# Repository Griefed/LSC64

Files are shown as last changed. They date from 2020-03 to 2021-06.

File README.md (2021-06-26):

# **This is still a WIP**
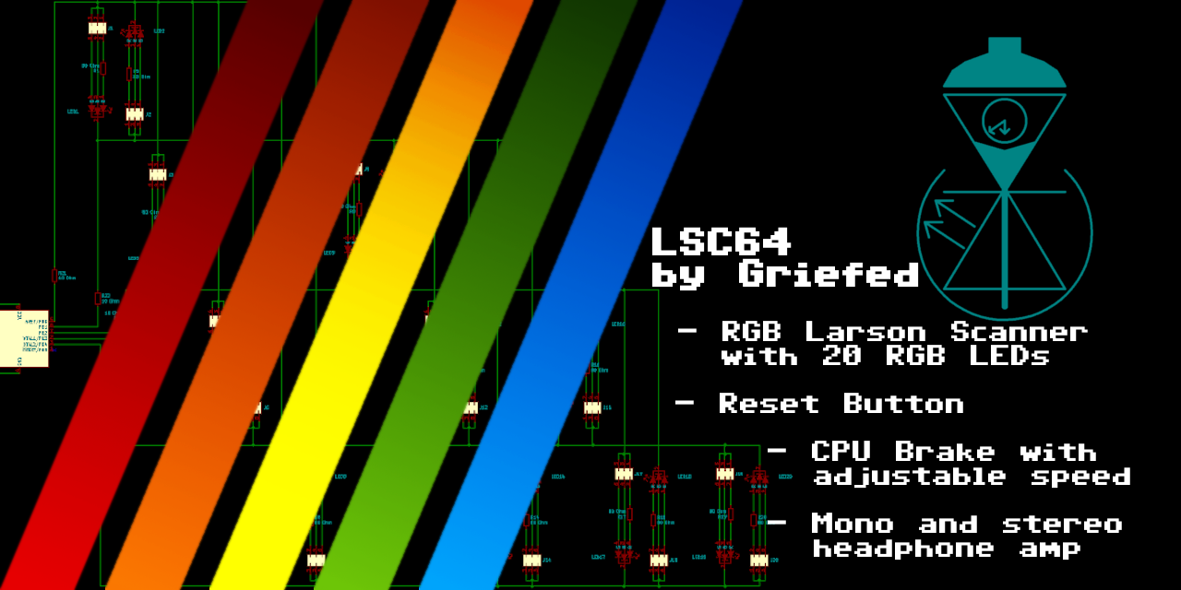
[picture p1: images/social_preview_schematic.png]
Social_Preview

# **This is still a WIP**

# Sources, GitHub, GitLab and Mirroring and all that good stuff

Repositories on GitHub are now for issues only. I've set up my own installation of GitLab and moved all my repositories over to [Git.Griefed.de](https://git.griefed.de/users/Griefed/projects). Make sure to check there first for the latest code before opening an issue on GitHub.

For questions, you can always join my [Discord server](https://discord.griefed.de) and talk to me there.

---

[[_TOC_]]

**This has yet to be tested IRL. I currently don't have the funds to procure the PCB and parts in order to build and test it. No guarantee on anything as of yet. Also, the code for the Attiny85 has yet to be written, reason: See above.**
----
## Features

A PCB to enhance your C64C with various things:
- A Larson Scanner with RGB LEDs, so you can configure it to your liking!
- An Expansion Port reset circuit. You just need to connect a button and off you go!
- A CPU brake: Throttle your CPU and slow down your game during the really tricky bits!
- Mono & Stereo Headphone Amp. Listen to the beautiful SID sounds with your headphones. Either in mono or in stereo, if you have an FPGA SID!

## Assembly

After getting the PCB printed the the printing service of your choice and getting all the parts from the vendor of your choice, take a good look at [the interactive BOM](BOMinteractive.html).
It's a nice interactive overview of the whole PCB, which helps you placing all your parts where they're supposed to be! (You need to download )
Thanks to the Open Scope Project on GitHub for this amazing KiCad plugin: [InteractiveHtmlBom](https://github.com/openscopeproject/InteractiveHtmlBom)

## Connecting your LSC64

### Larson Scanner

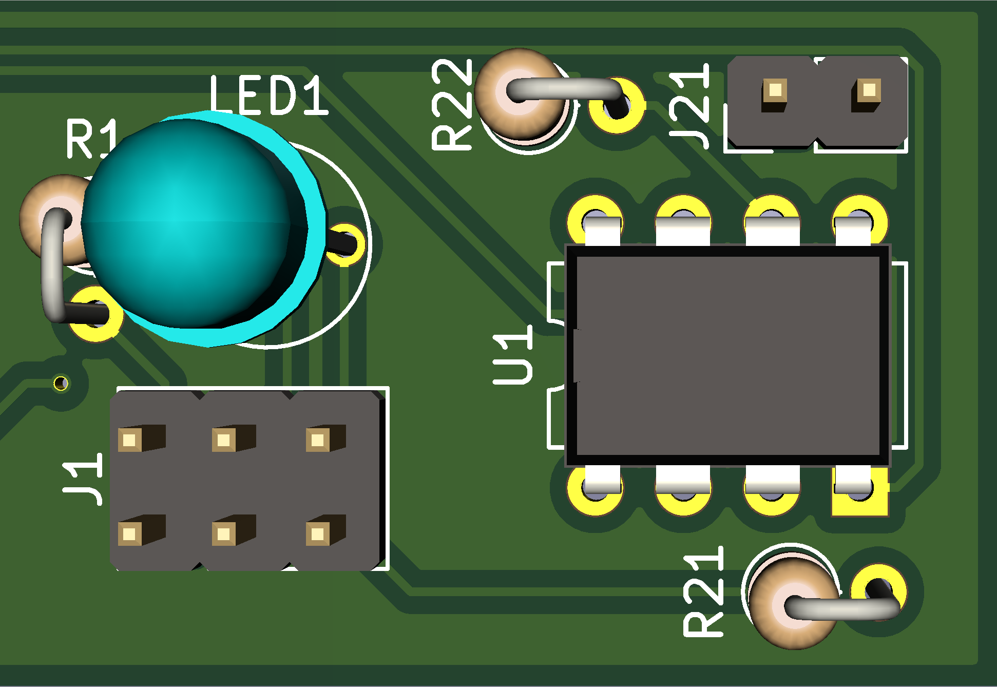
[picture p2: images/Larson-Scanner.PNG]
Larson


For information about the pin layout of the power connector, check out: [C64 Power Supply Connector](https://www.c64-wiki.com/wiki/Power_Supply_Connector)

The bottom 3 pins of J1 to J20 are all the same. The top 3 pins of J1 to J20 represent one colour of the RGB LED each.
From left to right: red, blue green.
So, to set the colours of the LED:

| From | Of | To | Of | Colour |
|:---|:---:|:---:|---:|:---:|
| Any of J21 | LSC64 | Pin 5 (+5V DC) | [C64 Power Supply Connector](https://www.c64-wiki.com/wiki/Power_Supply_Connector)| -x- |
| Any of J21 | LSC64 | J24 | LSC64 | -x- |
| Any of J26 | LSC64 | Pin 2 (GND) | [C64 Power Supply Connector](https://www.c64-wiki.com/wiki/Power_Supply_Connector)| -x- |
| J1 to J20 - Bottom Row| LSC64 | J1 to J20 - Top Left | LSC64 | Red |
| J1 to J20 - Bottom Row| LSC64 | J1 to J20 - Top Middle | LSC64 | Blue |
| J1 to J20 - Bottom Row| LSC64 | J1 to J20 - Top Right | LSC64 | Green  |

**Caution: Enabling more than one colour may result in the LED not lighting up at all. That is due to the output capacity of the Attiny85.**

**I recommend you only have one colour per LED enabled at all times.**

Special thanks to Luc Volders for the explanations and examples on how to build a charlieplexed Larson Scanner: [Luc's Tech Blog post about his Larson Scanner](https://lucstechblog.blogspot.com/2017/09/charlieplexing.html)

### The Reset Button

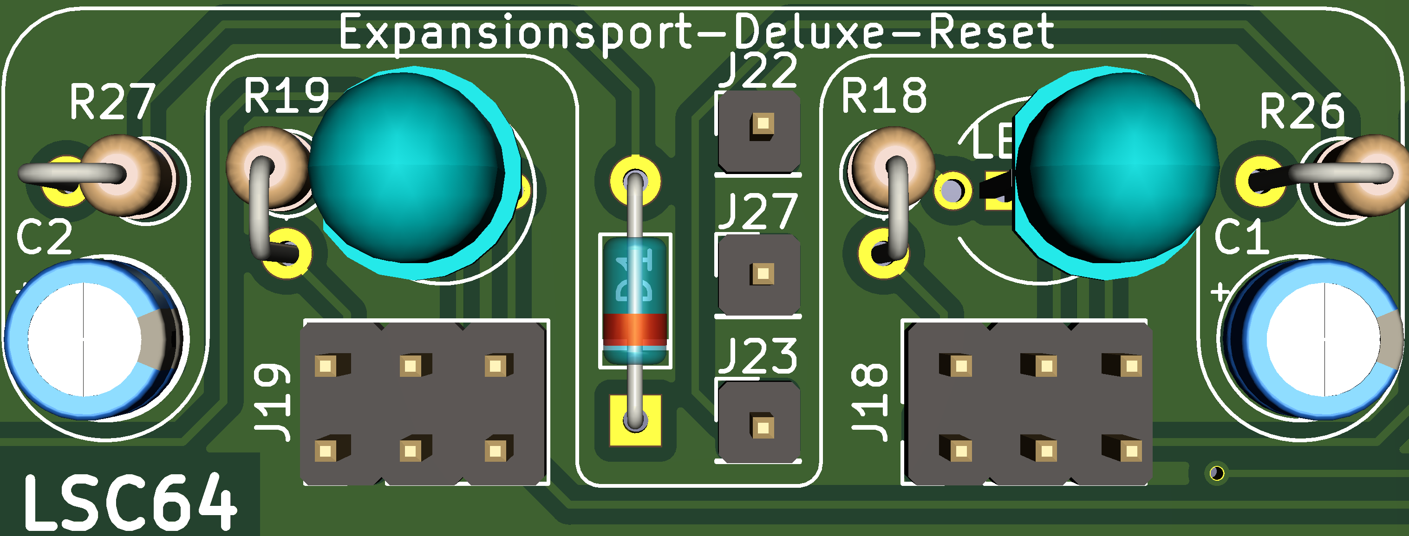
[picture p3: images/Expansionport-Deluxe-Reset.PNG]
Reset


| From | Of | To | Of |
|:---|:---:|:---:|---:|
| J22 | LSC64 | Pin C (RESET) | [C64 Expansion Port](https://www.c64-wiki.com/wiki/Expansion_Port) |
| J27 | LSC64 | Pin 9 (EXROM) | [C64 Expansion Port](https://www.c64-wiki.com/wiki/Expansion_Port) |
| J23 | LSC64 | Pin 1 | [Button](https://www.digikey.de/product-detail/de/e-switch/RP3502MABLK/EG1932-ND/280450?cur=EUR&lang=de)|
| Any of J26 | LSC64 | Pin 2 | [Button](https://www.digikey.de/product-detail/de/e-switch/RP3502MABLK/EG1932-ND/280450?cur=EUR&lang=de)|

Special thanks to AntaBaka for the schematics and the idea: [Expansionport-Deluxe-Reset](http://pitsch.de/stuff/c64/index_c64.htm#A24)

### CPU Brake

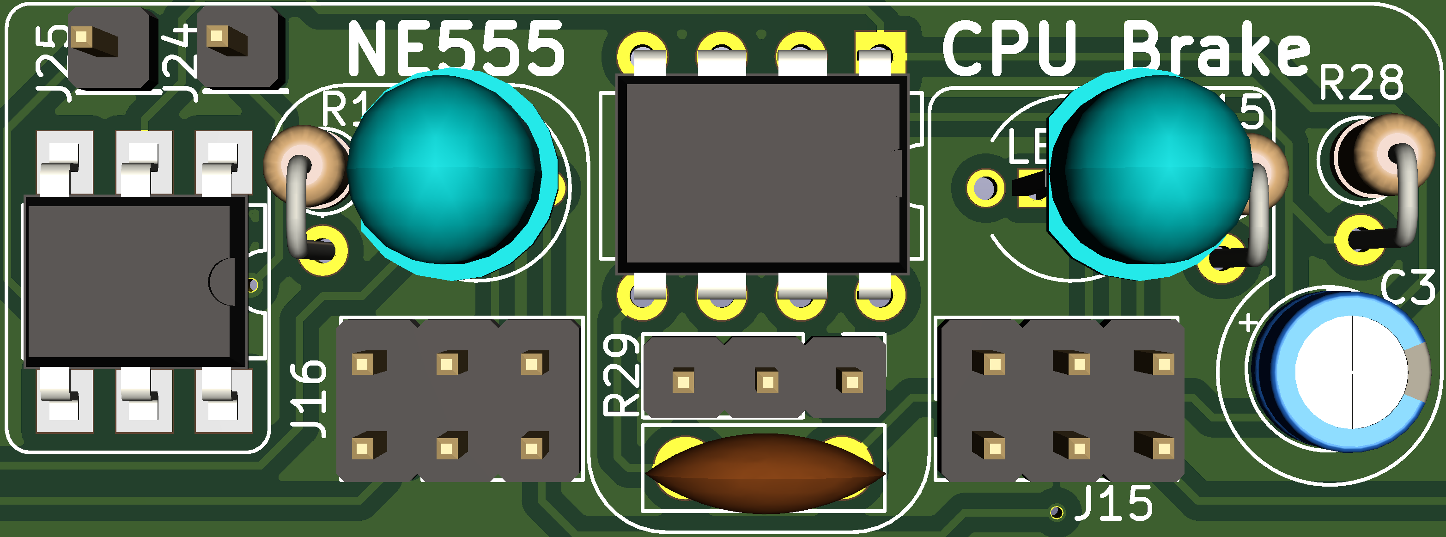
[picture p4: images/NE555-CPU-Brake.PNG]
CPUBrake


| From | Of | To | Of |
|:---|:---:|:---:|---:|
| Pin 1 | On/Off Switch | J21 | LSC64 |
| Pin 2 | On/Off Switch | J24 | LSC64 |
| Terminal 1 | Dual Potentiometer | Right Pin R29 | LSC64 |
| Terminal 2 | Dual Potentiometer | Middle Pin R29 | LSC64 |
| Terminal 3 | Dual Potentiometer | Left Pin R29 | LSC64 |
| J25 | LSC64 | Pin 4 (IRQ) | [C64 Expansion Port](https://www.c64-wiki.com/wiki/Expansion_Port)|

Special thanks to AntaBaka for the schematics and the idea: [CPU Brake NE555](http://pitsch.de/stuff/c64/index_c64.htm#A41)

### Mono-Stereo Headphone examples

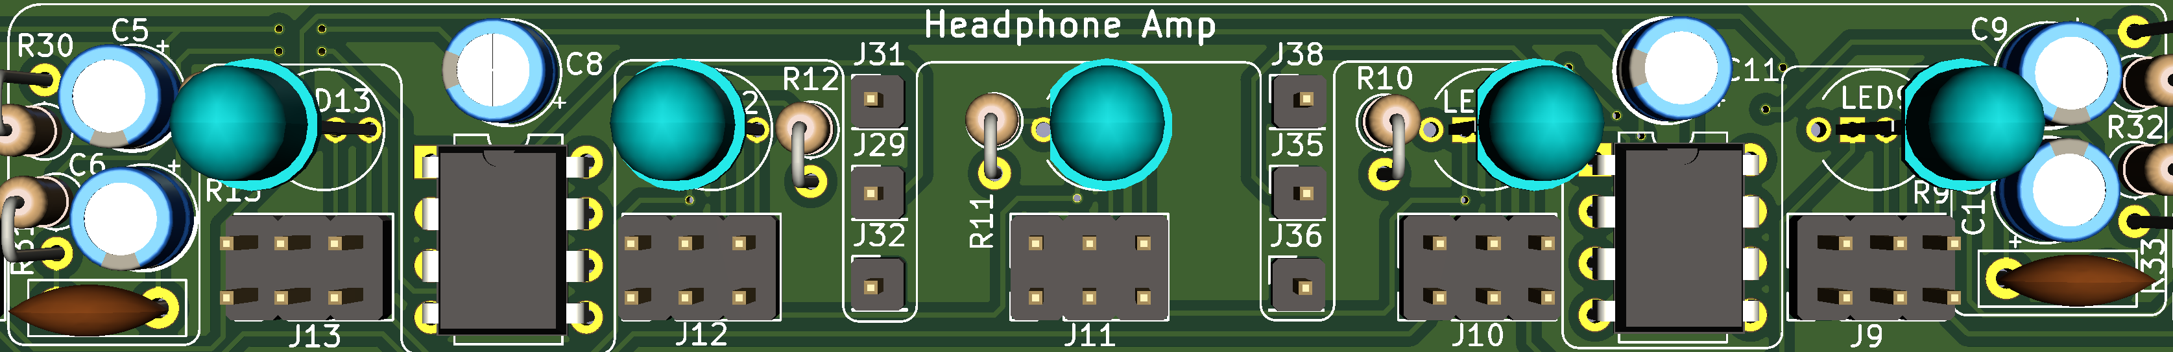
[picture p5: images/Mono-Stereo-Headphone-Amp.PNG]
Amp


##### CAUTION
- **Boards with assembly no. 250469 have no VR1. Check beforehand!**
- **Stereo sound REQUIRES an [FPGA SID](https://webstore.kryoflux.com/catalog/product_info.php?cPath=27&products_id=63&language=en)!**

| From | Of | To | Of |
|:---|:---:|:---:|---:|
| J31 | LSC64 | Pin 7 & 9 | Rotary Switch |
| J29 | LSC64 | Pin 2 | Dual Potentiometer |
| J35 | LSC64 | Pin 12 | Rotary Switch |
| J36 | LSC64 | Pin 5 | Dual Potentiometer |
| Pin 15 & 16 | Rotary Switch | Pin 2 | [VR1](images/Amp_Power_Supply.PNG) |
| Pin 1 | Dual Potentiometer | Pin 3 (AUDIO_OUT) | [C64 A/V connector](https://www.c64-wiki.com/wiki/A/V_Jack)|
| Pin 4 | Dual Potentiometer | Pin 7 (FPGA SID AUDIO OUT)| [C64 A/V connector](https://www.c64-wiki.com/wiki/A/V_Jack)|
| Pin 3 & 6 | Dual Potentiometer | Any of J26 | LSC64 |
| J32 | LSC64 | Pin 13 | Rotary Switch |
| J38 | LSC64 | Pin 14 | Rotary Switch |
| Pin 1 | Rotary Switch | Pin 2 (Tip) & Pin 3 (Ring)| Headphone Jack Mono |
| Pin 1 (Sleeve)| Headphone Jack Mono  | Any of J26 | LSC64 |
| Pin 3 | Rotary Switch | Pin 2 (Tip) | Headphone Jack Stereo |
| Pin 6 | Rotary Switch | Pin 3 (Ring) | Headphone Jack Stereo |
| Pin 1 (Sleeve)| Headphone Jack Stereo| Any of J26 | LSC64 |

**Additional parts required but not listed in the InteractiveHtmlBom (They're not a physical part of the LSC64 PCB)**
- **4x3 rotary switch** (e.g.:[Symbol](images/Rotary_Switch4x3.PNG), [Datasheet Model A403](https://dznh3ojzb2azq.cloudfront.net/products/Rotary/A/documents/datasheet.pdf), [Product page](https://www.digikey.de/product-detail/de/c-k/A40315RNZQ/CKC7008-ND/181440)).
- **dual potentiometer to change the volume** (e.g.:[Symbol](images/Dual_Potentiometer.PNG), [Datasheet](https://www.bourns.com/docs/Product-Datasheets/PDB18.pdf), [Product page](https://www.digikey.de/product-detail/de/bourns-inc/PDB182-K430K-104A/PDB182-K430K-104A-ND/3780721)).
- **Audio jack to plug in your headphones** (e.g.: [Datasheet](https://us.schurter.com/bundles/snceschurter/epim/_ProdPool_/newDS/en/typ_4832.2300.pdf), [Product page](https://www.digikey.de/product-detail/de/schurter-inc/4832-2300/486-3419-ND/1731055)).

Special thanks to AntaBaka for the schematics and the idea [Headphone Amp Mono](http://pitsch.de/stuff/c64/index_amp.htm) and Minidisc.org for the stereo schematics [HeadBanger Headphone Amp](http://www.minidisc.org/headbanger.html)

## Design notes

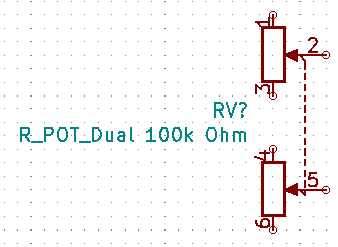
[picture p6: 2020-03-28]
images/Dual_Potentiometer.PNG

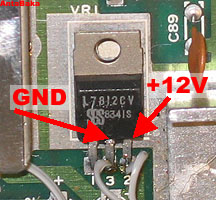
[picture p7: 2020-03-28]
images/Amp_Power_Supply.PNG

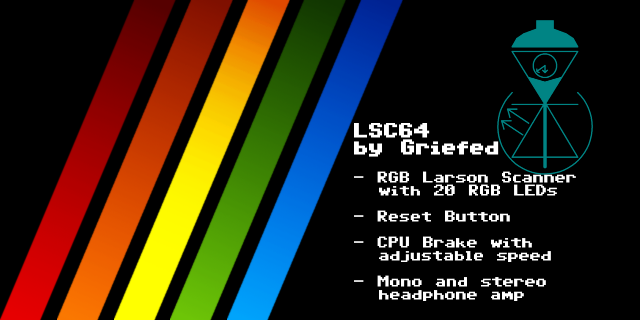
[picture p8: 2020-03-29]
images/Social_Preview_small.PNG

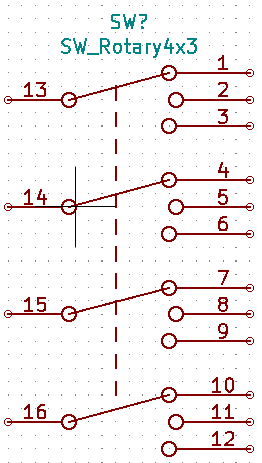
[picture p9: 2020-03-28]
images/Rotary_Switch4x3.PNG

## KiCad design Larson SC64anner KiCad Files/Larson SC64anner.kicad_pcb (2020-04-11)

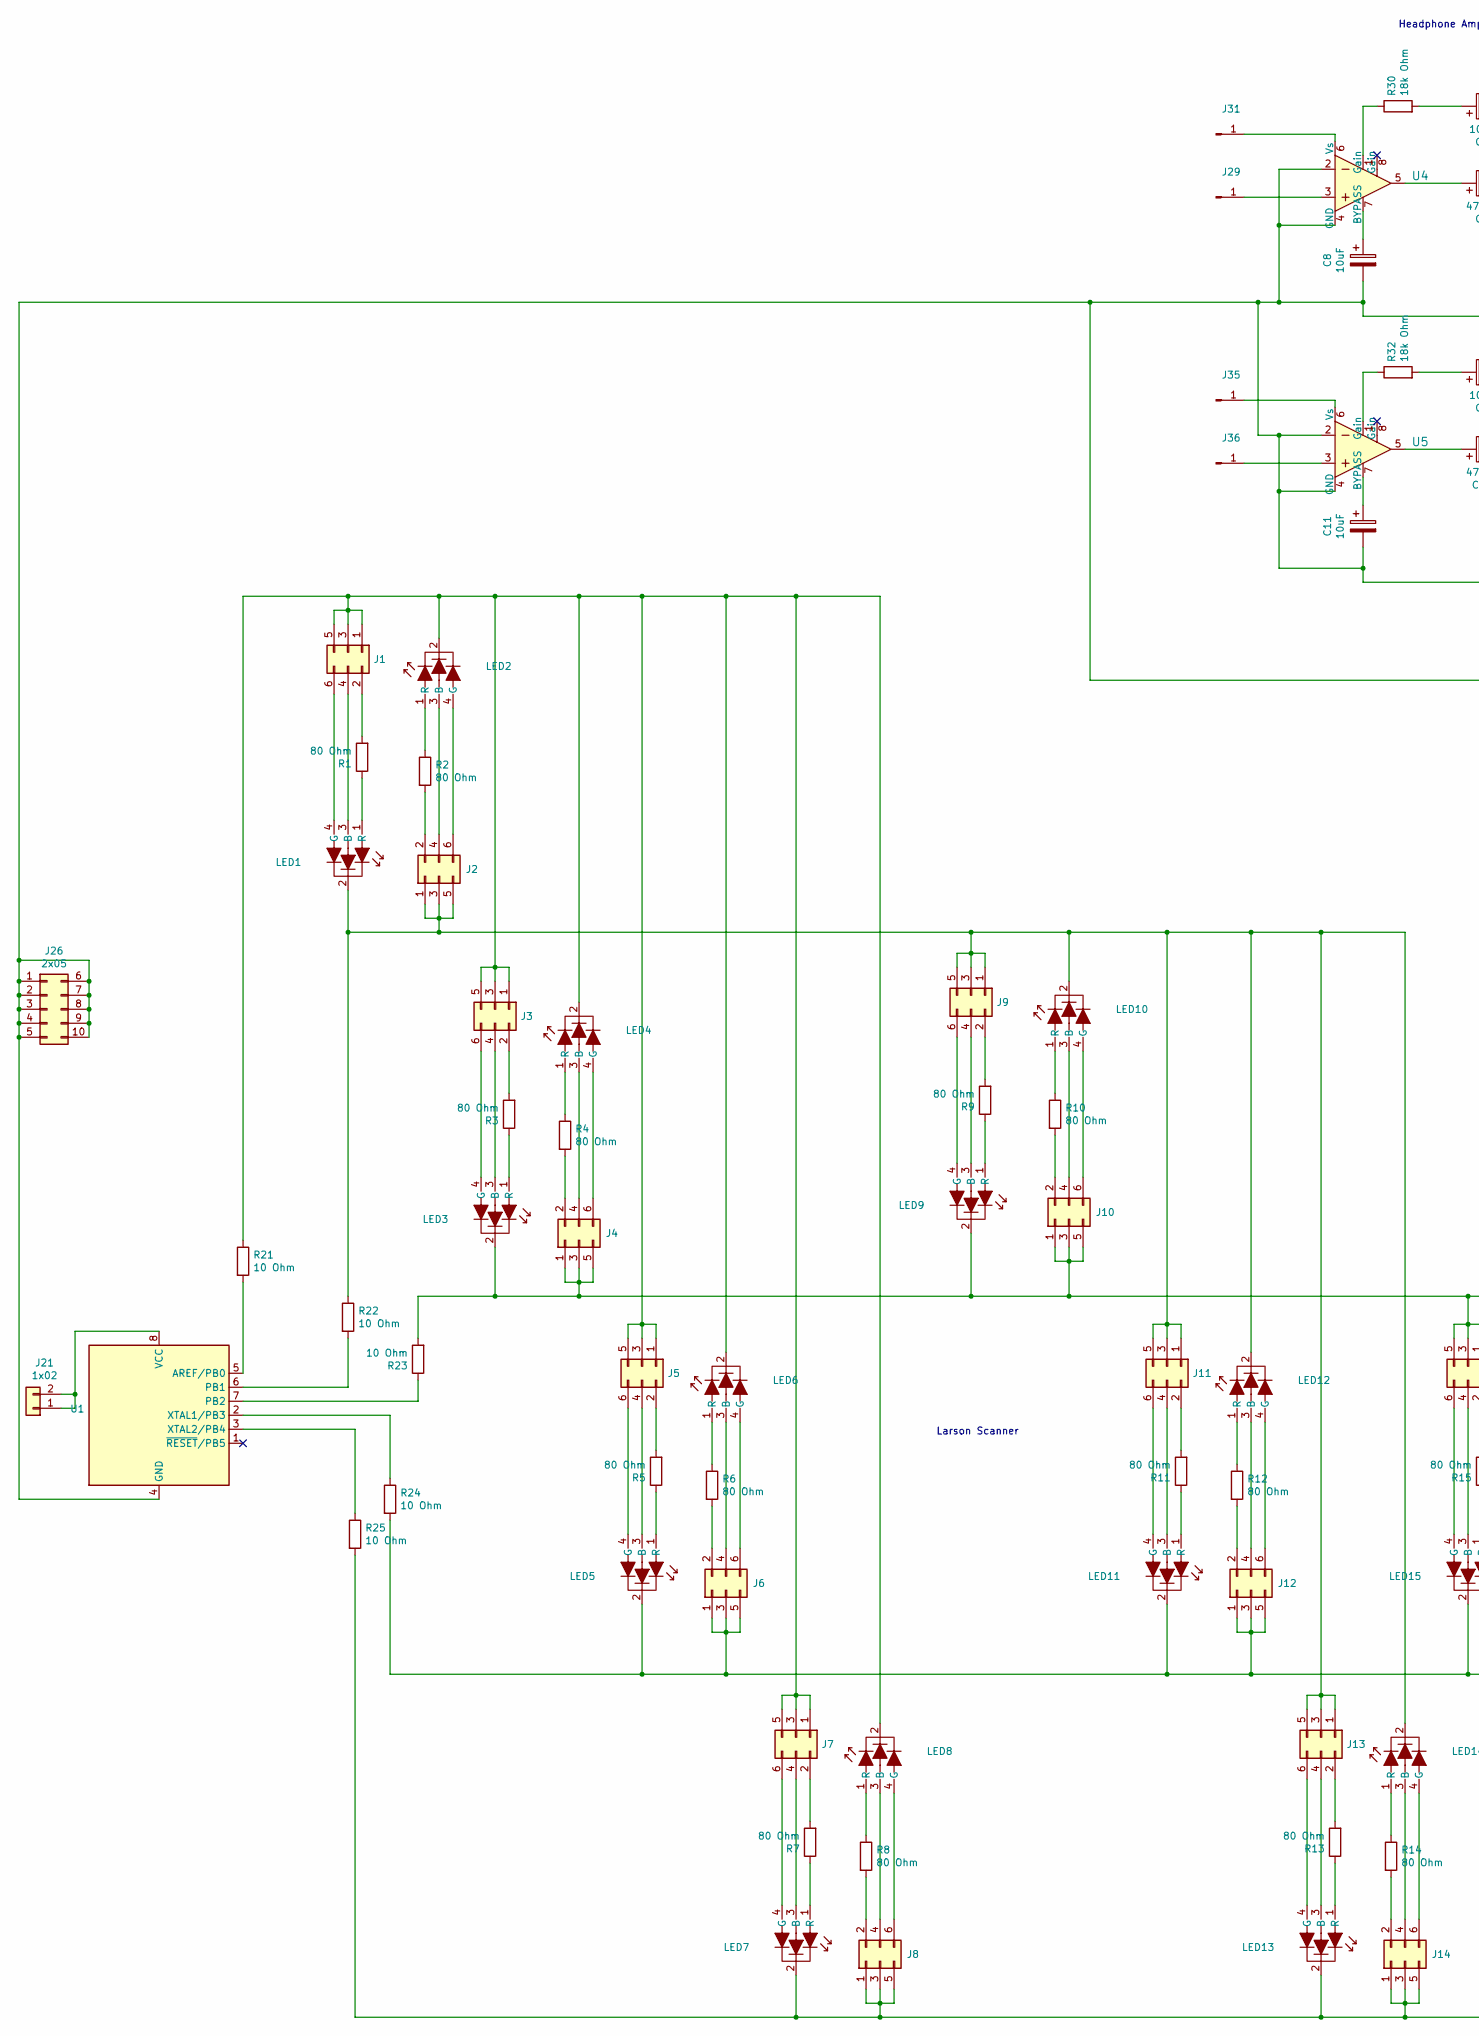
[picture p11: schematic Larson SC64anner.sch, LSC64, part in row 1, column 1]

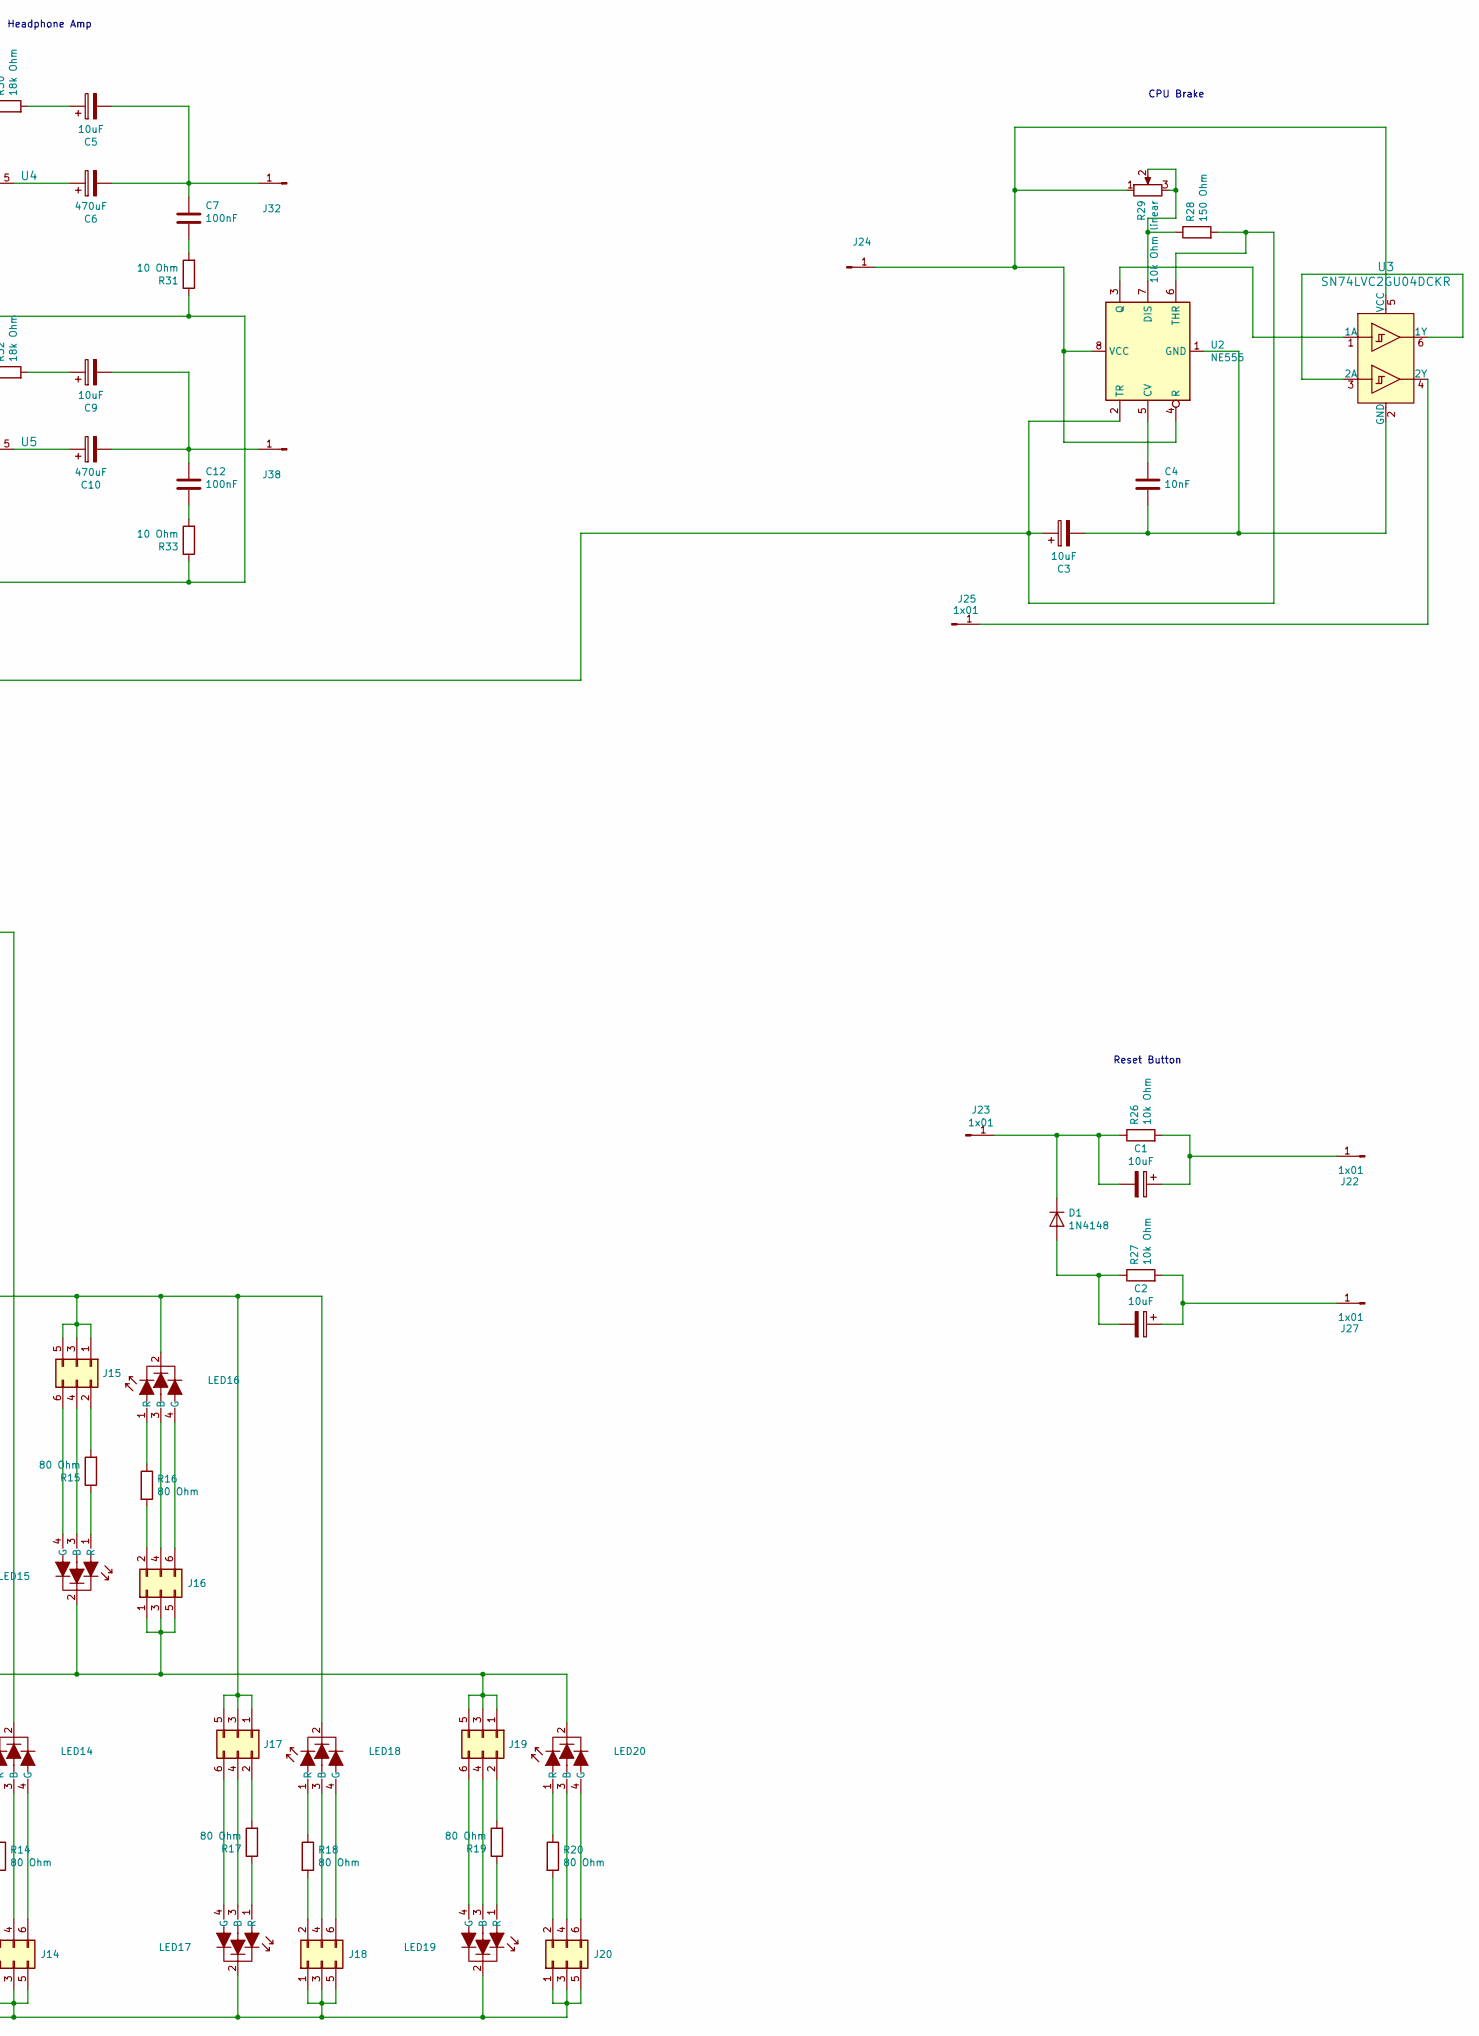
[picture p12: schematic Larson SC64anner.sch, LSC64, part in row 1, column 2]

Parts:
C1, C2, C3, C5, C8, C9, C11: 10uF; CP_Radial_D5.0mm_P2.50mm
C4: 10nF; C_Disc_D7.5mm_W2.5mm_P5.00mm
C6, C10: 470uF; CP_Radial_D5.0mm_P2.50mm
C7, C12: 100nF; C_Disc_D7.5mm_W2.5mm_P5.00mm
D1: 1N4148; D_DO-35_SOD27_P7.62mm_Horizontal
J1, J2, J3, J4, J5, J6, J7, J8, J9, J10, J11, J12, J13, J14, J15, J16, J17, J18, J19, J20: 2x03; PinHeader_2x03_P2.54mm_Vertical
J21: 1x02; PinHeader_1x02_P2.54mm_Vertical
J22, J23, J24, J25, J27, J29, J31, J32, J35, J36, J38: 1x01; PinHeader_1x01_P2.54mm_Vertical
J26: 2x05; PinHeader_2x05_P2.54mm_Vertical
LED1, LED2, LED3, LED4, LED5, LED6, LED7, LED8, LED9, LED10, LED11, LED12, LED13, LED14, LED15, LED16, LED17, LED18, LED19, LED20: LED_CRGB; LED_RGB_WP154A4SUREQBFZGC
R1, R2, R3, R4, R5, R6, R7, R8, R9, R10, R11, R12, R13, R14, R15, R16, R17, R18, R19, R20: 80 Ohm; R_Axial_DIN0207_L6.3mm_D2.5mm_P2.54mm_Vertical_reduced_cour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
R21, R22, R23, R24, R25, R31, R33: 10 Ohm; R_Axial_DIN0207_L6.3mm_D2.5mm_P2.54mm_Vertical_reduced_cour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
R26, R27: 10k Ohm; R_Axial_DIN0207_L6.3mm_D2.5mm_P2.54mm_Vertical_reduced_cour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
R28: 150 Ohm; R_Axial_DIN0207_L6.3mm_D2.5mm_P2.54mm_Vertical_reduced_cour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
R29: 10k Ohm linear; PinHeader_1x03_P2.54mm_Vertical
R30, R32: 18k Ohm; R_Axial_DIN0207_L6.3mm_D2.5mm_P2.54mm_Vertical_reduced_cour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
U1: ATtiny85V-20PU; DIP-8_W7.62mm
U2: NE555; DIP-8_W7.62mm
U3: SN74LVC2GU04DCKR; SMDIP-6_W7.62mm
U4, U5: LM386N-4_NOPB; DIP-8_W7.62mm; MPN LM386N-4/NOPB; Digi-Key_PN 296-43960-5-ND

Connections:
unnamed: C1.1, J22.1, R26.2
unnamed: C1.2, D1.1 (K), J23.1, R26.1
unnamed: C2.1, J27.1, R27.2
unnamed: C2.2, D1.2 (A), R27.1
unnamed: C3.2, C4.2, U2.1 (GND), U3.2 (GND)
unnamed: C4.1, U2.5 (CV)
unnamed: C5.1, R30.2
unnamed: C5.2, C6.2, C7.1, J32.1
unnamed: C6.1, U4.5
unnamed: C7.2, R31.2
unnamed: C8.1, U4.7 (BYPASS)
unnamed: C9.1, R32.2
unnamed: C10.1, U5.5
unnamed: C9.2, C10.2, C12.1, J38.1
unnamed: C11.1, U5.7 (BYPASS)
unnamed: C3.1, C8.2, C11.2, J26.1, J26.2, J26.3, J26.4, J26.5, J26.6, J26.7, J26.8, J26.9, J26.10, R28.2, R31.1, R33.1, U1.4 (GND), U2.2 (TR), U2.6 (THR), U4.2, U4.4 (GND), U5.2, U5.4 (GND)
unnamed: C12.2, R33.2
unnamed: J1.1, J1.3, J1.5, J3.1, J3.3, J3.5, J5.1, J5.3, J5.5, J7.1, J7.3, J7.5, LED2.2, LED4.2, LED6.2, LED8.2, R21.1
unnamed: J1.2, R1.2
unnamed: J1.4, LED1.3 (B)
unnamed: J1.6, LED1.4 (G)
unnamed: J2.2, R2.2
unnamed: J2.4, LED2.3 (B)
unnamed: J2.6, LED2.4 (G)
unnamed: J3.2, R3.2
unnamed: J3.4, LED3.3 (B)
unnamed: J3.6, LED3.4 (G)
unnamed: J4.2, R4.2
unnamed: J4.4, LED4.3 (B)
unnamed: J4.6, LED4.4 (G)
unnamed: J5.2, R5.2
unnamed: J5.4, LED5.3 (B)
unnamed: J5.6, LED5.4 (G)
unnamed: J6.2, R6.2
unnamed: J6.4, LED6.3 (B)
unnamed: J6.6, LED6.4 (G)
unnamed: J7.2, R7.2
unnamed: J7.4, LED7.3 (B)
unnamed: J7.6, LED7.4 (G)
unnamed: J8.2, R8.2
unnamed: J8.4, LED8.3 (B)
unnamed: J8.6, LED8.4 (G)
unnamed: J9.2, R9.2
unnamed: J9.4, LED9.3 (B)
unnamed: J9.6, LED9.4 (G)
unnamed: J4.1, J4.3, J4.5, J10.1, J10.3, J10.5, J15.1, J15.3, J15.5, J17.1, J17.3, J17.5, LED3.2, LED9.2, LED16.2, LED18.2, R23.2
unnamed: J10.2, R10.2
unnamed: J10.4, LED10.3 (B)
unnamed: J10.6, LED10.4 (G)
unnamed: J2.1, J2.3, J2.5, J9.1, J9.3, J9.5, J11.1, J11.3, J11.5, J13.1, J13.3, J13.5, LED1.2, LED10.2, LED12.2, LED14.2, R22.1
unnamed: J11.2, R11.2
unnamed: J11.4, LED11.3 (B)
unnamed: J11.6, LED11.4 (G)
unnamed: J6.1, J6.3, J6.5, J12.1, J12.3, J12.5, J16.1, J16.3, J16.5, J19.1, J19.3, J19.5, LED5.2, LED11.2, LED15.2, LED20.2, R24.2
unnamed: J12.2, R12.2
unnamed: J12.4, LED12.3 (B)
unnamed: J12.6, LED12.4 (G)
unnamed: J13.2, R13.2
unnamed: J13.4, LED13.3 (B)
unnamed: J13.6, LED13.4 (G)
unnamed: J8.1, J8.3, J8.5, J14.1, J14.3, J14.5, J18.1, J18.3, J18.5, J20.1, J20.3, J20.5, LED7.2, LED13.2, LED17.2, LED19.2, R25.2
unnamed: J14.2, R14.2
unnamed: J14.4, LED14.3 (B)
unnamed: J14.6, LED14.4 (G)
unnamed: J15.2, R15.2
unnamed: J15.4, LED15.3 (B)
unnamed: J15.6, LED15.4 (G)
unnamed: J16.2, R16.2
unnamed: J16.4, LED16.3 (B)
unnamed: J16.6, LED16.4 (G)
unnamed: J17.2, R17.2
unnamed: J17.4, LED17.3 (B)
unnamed: J17.6, LED17.4 (G)
unnamed: J18.2, R18.2
unnamed: J18.4, LED18.3 (B)
unnamed: J18.6, LED18.4 (G)
unnamed: J19.2, R19.2
unnamed: J19.4, LED19.3 (B)
unnamed: J19.6, LED19.4 (G)
unnamed: J20.2, R20.2
unnamed: J20.4, LED20.3 (B)
unnamed: J20.6, LED20.4 (G)
unnamed: J21.1, J21.2, U1.8 (VCC)
unnamed: J24.1, R29.1, U2.4 (R), U2.8 (VCC), U3.5 (VCC)
unnamed: J25.1, U3.4 (2Y)
unnamed: J29.1, U4.3
unnamed: J31.1, U4.6 (Vs)
unnamed: J35.1, U5.6 (Vs)
unnamed: J36.1, U5.3
unnamed: LED1.1 (R), R1.1
unnamed: LED2.1 (R), R2.1
unnamed: LED3.1 (R), R3.1
unnamed: LED4.1 (R), R4.1
unnamed: LED5.1 (R), R5.1
unnamed: LED6.1 (R), R6.1
unnamed: LED7.1 (R), R7.1
unnamed: LED8.1 (R), R8.1
unnamed: LED9.1 (R), R9.1
unnamed: LED10.1 (R), R10.1
unnamed: LED11.1 (R), R11.1
unnamed: LED12.1 (R), R12.1
unnamed: LED13.1 (R), R13.1
unnamed: LED14.1 (R), R14.1
unnamed: LED15.1 (R), R15.1
unnamed: LED16.1 (R), R16.1
unnamed: LED17.1 (R), R17.1
unnamed: LED18.1 (R), R18.1
unnamed: LED19.1 (R), R19.1
unnamed: LED20.1 (R), R20.1
unnamed: R21.2, U1.5 (AREF/PB0)
unnamed: R22.2, U1.6 (PB1)
unnamed: R23.1, U1.7 (PB2)
unnamed: R24.1, U1.2 (XTAL1/PB3)
unnamed: R25.1, U1.3 (XTAL2/PB4)
unnamed: R28.1, R29.2, R29.3, U2.7 (DIS)
unnamed: R30.1, U4.1 (Gain)
unnamed: R32.1, U5.1 (Gain)
unnamed: U2.3 (Q), U3.1 (1A)
unnamed: U3.3 (2A), U3.6 (1Y)

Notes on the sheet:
Reset Button
CPU Brake
Headphone Amp
Larson Scanner

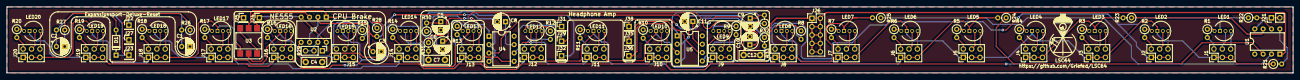
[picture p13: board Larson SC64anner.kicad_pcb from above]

Board: 2 copper layers, 390.0 x 20.0 mm, 104 parts (0 on the bottom side), 119 nets.

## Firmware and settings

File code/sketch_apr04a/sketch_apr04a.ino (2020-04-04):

//Charlieplexed Larson Scanner for C64 with Attiny85
//Code by Griefed, inspired by Luc Volders' Larson Scanner Tutorial

int pins[] = {0, 1, 2, 3, 4};
int numberpins = 5;
int i;
int j;
int k;
int slowdown = 2; //Less LEDs = Lower value e.g. 4 if 12 LEDs
long int start = 0;
long int ending = 0;

const int ledpins[20][2]=
  //Your LED array
  {
  {1,0},
  {0,1},
  {2,0},
  {0,2},
  {3,0},
  {0,3},
  {4,0},
  {0,4},
  {2,1},
  {1,2},
  {3,1},
  {1,3},
  {4,1},
  {1,4},
  {3,2},
  {2,3},
  {4,2},
  {2,4},
  {4,3},
  {3,4}
  };

void setup()
//Turn all LEDs off before we start
{
  alloff();
  delay(1000);
}

void loop()
//Larscon Scanner
{
  //Larson Scanner forward
  for (i=0; i<20; i++)
    {
    ledon(i);
    delay(1000);
    alloff();
    }
  //Larson Scanner backward
  for (i=19; i>-1; i--)
  {
    ledon(i);
    delay(1000);
    alloff();
  }
  alloff();
}

void alloff()
//Function to turn all LEDs off
{
  for(int k=0; k<5; k++)
  {
    pinMode (pins[k], INPUT);
  }
}

void ledon(int lednr)
//Turns an LED from the array on
{
  int pluspin = ledpins[lednr][0];
  int negpin = ledpins[lednr][1];
  
  pinMode (pluspin, OUTPUT);
  digitalWrite (pluspin, HIGH);

  pinMode (negpin, OUTPUT);
  digitalWrite (negpin, LOW);
  
  delay(slowdown);
}

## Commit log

2020-03-21 Add files via upload
    KiCad files for the PCB, schematic, netlist etc. etc.
    [Larson SC64anner-B_Cu.gbr, Larson SC64anner-B_Mask.gbr, Larson SC64anner-B_Paste.gbr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]
2020-03-21 Add files via upload
    KiCad library footprint and symbol files needed for the schematic and pcb
2020-03-28 Updated PCB
    - Touchups
    - Added mono / stereo headphone amp circuitry
    [Larson SC64anner.kicad_pcb, Larson SC64anner.sch]
2020-03-28 Updated ibom.html
    Updated bill of materials
2020-03-28 Cleand up Silk-Layer
    Minor beauty corrections
    [Larson SC64anner.kicad_pcb]
2020-03-28 Starting work on amp documentation
    Added screenshot of pcb part
    Edited README with additional information
2020-03-28 Cleanup and documentation
    - Deleted some unnecessary parts
    - Started description on how to connect the headphone amp circuitry
    [Larson SC64anner.kicad_pcb, Larson SC64anner.sch]
2020-03-29 Changed folder structure
    [Larson SC64anner-B_Cu.gbr, Larson SC64anner-B_Mask.gbr, Larson SC64anner-B_Paste.gbr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]
2020-03-29 Updated README, BOMinteractive and Mono-Stereo-Headphone-Amp.PNG
    [Larson SC64anner.kicad_pcb]
2020-03-29 PCB cleanup
    [Larson SC64anner-B_Cu.gbr, Larson SC64anner-B_Mask.gbr, Larson SC64anner-B_Paste.gbr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]
2020-03-29 Update Larson SC64anner.kicad_pcb-bak
2020-03-29 Cleaned up front silk layer
    [Larson SC64anner-B_Cu.gbr, Larson SC64anner-B_Mask.gbr, Larson SC64anner-B_Paste.gbr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]
2020-03-30 Re-arrange headphone amp circtuit
    Re-did and re-arranged the whole headphone amp circuitry into a more orderly fashion.
    [Larson SC64anner-B_Cu.gbr, Larson SC64anner-B_Mask.gbr, Larson SC64anner-B_Paste.gbr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]
2020-04-02 Updated PCB, README, Schmetic
    Simpliefied things a bit.
    [Larson SC64anner-B_Cu.gbr, Larson SC64anner-B_Mask.gbr, Larson SC64anner-B_Paste.gbr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]
2020-04-03 Updated README
    Switched the description of the connections from stupid text lists to tables. Much better!
    [Larson SC64anner-B_Cu.gbr, Larson SC64anner-B_Mask.gbr, Larson SC64anner-B_Paste.gbr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]
2020-04-03 Cleanup and corrections
    Cleaned up the pcb a bit and made new screenshots.
    Also fixed some more minor things in the README. Will it ever end? :D
    [Larson SC64anner-B_Cu.gbr, Larson SC64anner-B_Mask.gbr, Larson SC64anner-B_Paste.gbr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]
2020-04-03 Gerber Files
    Changed some settings of the gerber job files to fit PCBWay settings.
    [Larson SC64anner-B_Cu.gbr, Larson SC64anner-B_Mask.gbr, Larson SC64anner-B_Paste.gbr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]
2020-04-03 Update README.md
    Forgot to add the connection to ground. Whoops.
2020-04-04 Various
    -Added a sociel preview with the LED part of the schematic in the background
    -Filled the unsued zones of the pcb with copper fields, to increase production quality due to equal spread of copper layers (galvanic index)
    [Larson SC64anner-B_Cu.gbr, Larson SC64anner-B_Mask.gbr, Larson SC64anner-B_Paste.gbr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]
2020-04-05 Updated PCB
    -Cleaned up the silklayer which resulted in redoing screenshots and gerber files etc.
    [Larson SC64anner-B_Cu.gbr, Larson SC64anner-B_Mask.gbr, Larson SC64anner-B_Paste.gbr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]
2020-04-10 Minor touchups
    [Larson SC64anner-B_Cu.gbr, Larson SC64anner-B_Mask.gbr, Larson SC64anner-B_Paste.gbr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]
2020-04-10 More cleanups
    Cleaned the PCB up some more.
    [Larson SC64anner-B_Cu.gbr, Larson SC64anner-B_Mask.gbr, Larson SC64anner-B_Paste.gbr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]
2020-04-11 More cleanups
    [Larson SC64anner-B_Cu.gbr, Larson SC64anner-B_Mask.gbr, Larson SC64anner-B_Paste.gbr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]
